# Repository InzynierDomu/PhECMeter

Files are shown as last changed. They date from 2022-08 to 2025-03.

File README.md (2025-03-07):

# PhECMeter







- [PhECMeter](#phecmeter)
  - [Description](#description)
    - [Future](#future)
  - [Scheme](#scheme)
    - [Part list](#part-list)
  - [IDE](#ide)
  - [Quick deployment without using VS Code environment](#quick-deployment-without-using-vs-code-environment)
    - [Requirements](#requirements)
    - [Usage](#usage)
    - [Notes](#notes)

## Description
The video with the entire project can be watched on this [video](https://youtu.be/vjk0nq04lCo)

The device has 4 possible states:
* measure pH
* measure EC
* calibartion pH
* calibration EC



The device start in pH measure mode. To chnage pH/EC measure mode - press up button for more than 1s.</br>
To enter calibration mode press both buttons more 1s.</br>
Measure pH -> calibration pH.</br>
Measure EC -> calibartion EC.</br>
Calibration mode needs 2 points to save.</br>
Set the value to which sample the probe is immersed. For that use up and dwn(down) buttons to decrease or increase the value. In EC calibration possible is to change the digit position by pressing 1s up button. To save points press 1s on both buttons. After saving two points, the device changes state to measure.</br>
</br>
When SD card is plugged, after short press down button measurements will be save in file on SD.

<div align="center">
<h2>Support</h2>

<p>If any of my projects have helped you in your work, studies, or simply made your day better, you can buy me a coffee. <a href="https://buycoffee.to/inzynier-domu" target="_blank">Postaw mi kawę na buycoffee.to</a></p>
</div>

### Future
* Use accumulator.
* Add some communication maybe RS232 or RS485.

## Scheme
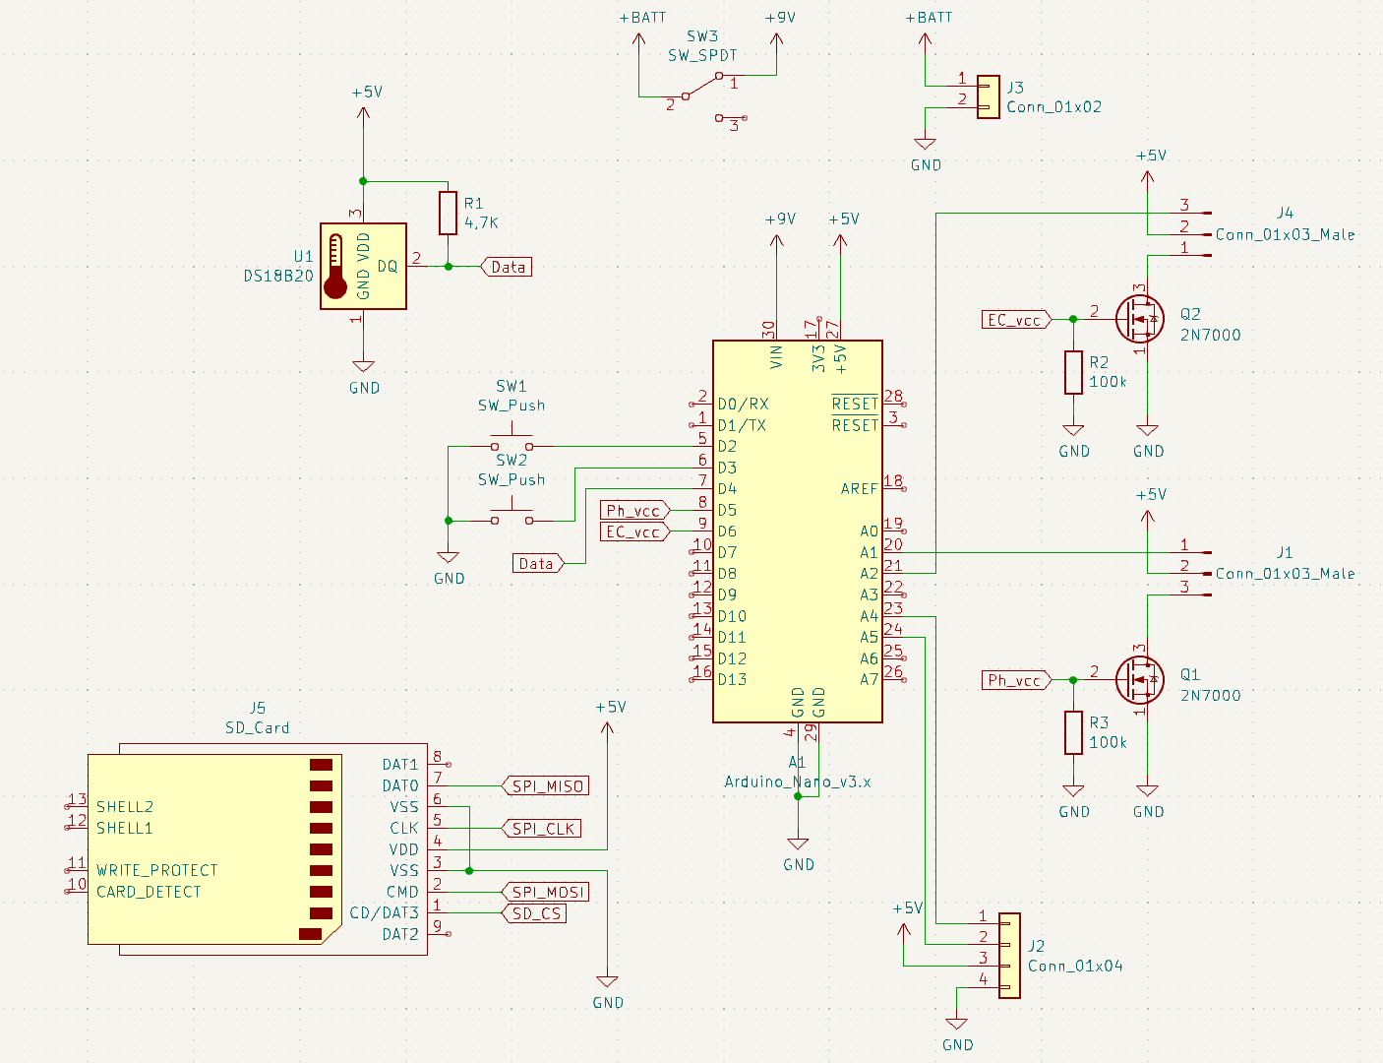
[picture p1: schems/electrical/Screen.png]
schem

### Part list
* pH probe and board like [this](https://botland.com.pl/pl/seria-gravity/15094-gravity-czujnik-miernik-ph-analogowy-v2-dfrobot-sen0161-v2.html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)
* EC probe and board like [this](https://botland.com.pl/gravity-czujniki-pogodowe/15096-gravity-analogowy-czujnik-zasolenia-wody-i-gleby-dfrobot-dfr0300-h-5904422348359.html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)
* A1 Arduino Nano
* U1 ds18b20 temperature sensor
* J1 is socket for pH board.
* J2 is socket for I2C screen OLED SSD1306 128x32 or HD44780 via PCF8574. 
* R1 Resistor 4,7 kohm
* SW1, SW2 micro switch
* SW3 switch to turning on/of power
* J3 connect to battery box
* J5 SD card socket (optional)

## IDE
If you prefer not to use the VS Code environment or prefer simpler solutions, you can use an [alternative approach](#quick-deployment-without-using-vs-code-environment)
For specific screen is the prepared environment:</br>
OLED SSD1306 128x32 :nanoatmega328_oled</br>
HD44780 via PCF8574 :nanoatmega328_lcd</br>
</br>
The project is prepared for the Platform IO environment. A video on how to install such an environment can be watched on this [video](https://youtu.be/Em9NuebT2Kc).
<br><br>
Formatting is done using clang-format. The description of the tool configuration is in the [video](https://youtu.be/xxuaOG0WjIE).
<br><br>
The code contains a comment prepared for doxygen, their use is described in the [video](https://youtu.be/1YKJtrCsPD4).

## Quick deployment without using VS Code environment
You don't need vscode, platformio is not needed, it will be installed with the script.

### Requirements
* Python 3.x must be installed on your computer. You can download the latest version of Python from Python.org.
### Usage
* Connect the Arduino board to your computer using a USB cable.
* Ensure that Python is available in the system environment.
* Run the autodeploy.bat file by double-clicking on it or running it from the command prompt (cmd). This script will automatically detect the connected Arduino board and upload the project to it.
### Notes
* It's version for oled.
* Make sure that the path to Python is added to the PATH environment variable in the Windows operating system.
* The atodeploy.bat script works only on Windows.

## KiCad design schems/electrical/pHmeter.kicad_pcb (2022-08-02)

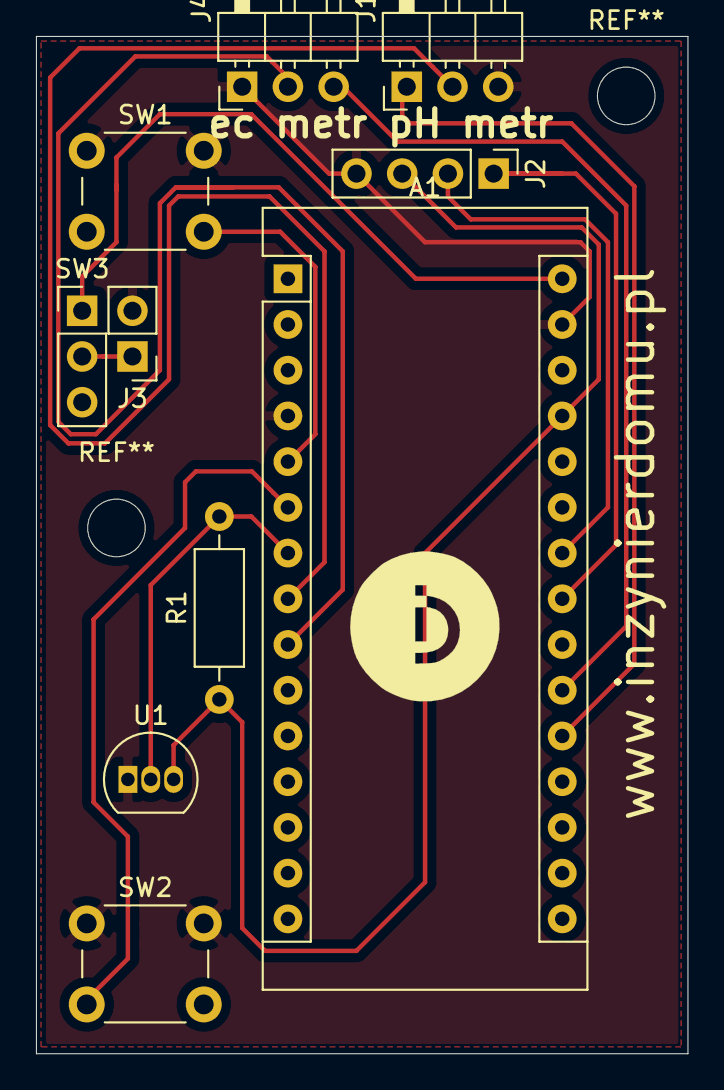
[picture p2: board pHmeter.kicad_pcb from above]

Board: 2 copper layers, 36.2 x 56.5 mm, 10 parts (0 on the bottom side), 13 nets.

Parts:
A1: Arduino_Nano_v3.x; Arduino_Nano
J1, J4: Conn_01x03_Male; PinHeader_1x03_P2.54mm_Horizontal
J2: Conn_01x04; PinHeader_1x04_P2.54mm_Vertical
J3: Conn_01x02; PinHeader_1x02_P2.54mm_Vertical
R1: 4,7K; R_Axial_DIN0207_L6.3mm_D2.5mm_P10.16mm_Horizontal
SW1, SW2: SW_Push; SW_PUSH_6mm_H8mm
SW3: SW_SPDT; PinHeader_1x03_P2.54mm_Vertical
U1: DS18B20; TO-92_Inline

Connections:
+5V: A1.27, J2.3, R1.1, U1.3
+9V: A1.30, SW3.1
+BATT: J3.1, SW3.2
Data: A1.7, R1.2, U1.2
EC_vcc: A1.9, J4.2
GND: A1.4, A1.29, J1.3, J2.4, J3.2, J4.1, SW1.1, SW2.1, U1.1
unnamed: A1.5, SW1.2
unnamed: A1.6, SW2.2
unnamed: A1.20, J1.1
unnamed: A1.21, J4.3
unnamed: A1.23, J2.1
unnamed: A1.24, J2.2
Ph_vcc: A1.8, J1.2

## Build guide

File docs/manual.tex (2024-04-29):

\documentclass{article}
\usepackage{graphicx}
\title{pH EC meter - Manual}
\author{Inżynier Domu - Szymon Markiewicz}
\date{October 2022}
\begin{document}
\maketitle
\tableofcontents

\section{Installation}
If you prefer not to use the VS Code environment or prefer simpler solutions, you can use an \href{#quick-deployment-without-using-vs-code-environment}{alternative approach}.

For specific screen is the prepared environment:
\begin{itemize}
    \item OLED SSD1306 128x32 : \texttt{nanoatmega328\_oled}
    \item HD44780 via PCF8574 : \texttt{nanoatmega328\_lcd}
\end{itemize}

The project is prepared for the Platform IO environment. A video on how to install such an environment can be watched on this \href{https://youtu.be/Em9NuebT2Kc}{video}.

\subsection{Quick deployment without using VS Code environment}
You don't need vscode, platformio is not needed, it will be installed with the script.

\subsubsection{Requirements}
\begin{itemize}
    \item Python 3.x must be installed on your computer. You can download the latest version of Python from \href{https://www.python.org}{Python.org}.
\end{itemize}

\subsubsection{Usage}
\begin{itemize}
    \item Connect the Arduino board to your computer using a USB cable.
    \item Ensure that Python is available in the system environment.
    \item Run the autodeploy.bat file by double-clicking on it or running it from the command prompt (cmd). This script will automatically detect the connected Arduino board and upload the project to it.
\end{itemize}

\subsubsection{Notes}
\begin{itemize}
    \item It's version for OLED.
    \item Make sure that the path to Python is added to the PATH environment variable in the Windows operating system.
    \item The atodeploy.bat script works only on Windows.
\end{itemize}

\section{Usage}
The video with the entire project can be watched on this \href{https://youtu.be/vjk0nq04lCo}{video}.

The device has 4 possible states:
\begin{itemize}
    \item measure pH
    \item measure EC
    \item calibration pH
    \item calibration EC
\end{itemize}

The device starts in pH measure mode. To change pH/EC measure mode - press the up button for more than 1 second. To enter calibration mode, press both buttons for more than 1 second. 
\begin{itemize}
    \item Measure pH -> calibration pH.
    \item Measure EC -> calibration EC.
\end{itemize}
Calibration mode requires 2 points to be saved.

Set the value to which the sample probe is immersed. Use the up and down buttons to decrease or increase the value. In EC calibration, it is possible to change the digit position by pressing the up button for 1 second. To save points, press both buttons for 1 second. After saving two points, the device changes state to measure.

When an SD card is plugged in, after a short press of the down button, measurements will be saved in a file on the SD card.

\end{document}

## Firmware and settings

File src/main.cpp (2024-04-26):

/**
 * @file main.cpp
 * @author by Szymon Markiewicz (https://github.com/InzynierDomu/)
 * @brief pH and EC meter
 * @date 2022-06
 */

#include "Buttons.h"
#include "Calibration_data_memory.h"
#include "Config.h"
#include "DS18B20.h"
#include "Data_presentation.h"
#include "Linear_function.h"
#include "OneWire.h"
#include "Sd_card.h"

#include <Arduino.h>
#include <EEPROM.h>
#include <math.h>

///< possible device state
enum class Device_state
{
  startup,
  display_measure_ph,
  display_measure_ec,
  calibration_ph,
  calibration_ec
};

byte m_ds_address[8]; ///< ds18b20 thermometer one wire address
OneWire m_one_wire = OneWire(Config::pin_thermometer); ///< one wire bus
DS18B20 m_ds_sensor = DS18B20(Config::pin_thermometer); ///< ds18b20 thermometer
Data_presentation m_data_presentation; ///< screen and serial handling
Calibration_data_memory m_memory; ///< memory handling
Sd_card m_sd_card; ///< sd crad handling

Device_state m_device_state = Device_state::startup; ///< actual device state

volatile bool m_up_button_pressed = false; ///< right button pressed flag
volatile bool m_dwn_button_pressed = false; ///< left button pressed flag
Linear_function ph_probe_characteristic; ///< ph probe linear characteristic
Linear_function ec_probe_characteristic; ///< ec probe linear characteristic

/**
 * @brief find thermometer on one wire
 */
void ds_thermometer_init()
{
  m_one_wire.reset_search();
  while (m_one_wire.search(m_ds_address))
  {
    if (m_ds_address[0] != 0x28)
      continue;

    if (OneWire::crc8(m_ds_address, 7) != m_ds_address[7])
    {
      break;
    }
  }
}

/**
 * @brief right button press interrupt
 */
void button_r_pressed()
{
  m_up_button_pressed = true;
}

/**
 * @brief left button press interrupt
 */
void button_l_pressed()
{
  m_dwn_button_pressed = true;
}

/**
 * @brief ph measure
 * @param action: buttons action
 */
void measurements_ph(const Buttons_action action)
{
  float temperature = m_ds_sensor.getTempC();
  int analog_mes = analogRead(Config::ph_pin_probe);
  float ph = ph_probe_characteristic.find_unit_val(analog_mes);

  m_data_presentation.measurements_ph(temperature, ph);

  switch (action)
  {
    case Buttons_action::two_buttons_long:
      m_data_presentation.calibration_mode();
      m_device_state = Device_state::calibration_ph;
      break;
    case Buttons_action::up_button_long:
      digitalWrite(Config::ph_supply_pin_probe, LOW);
      digitalWrite(Config::ec_supply_pin_probe, HIGH);
      m_device_state = Device_state::display_measure_ec;
      break;
    case Buttons_action::short_dwn_button:
      if (m_sd_card.get_card_status())
      {
        m_sd_card.save_ph_measurement(temperature, ph);
        m_data_presentation.save_data();
      }
      break;
    default:
      m_device_state = Device_state::display_measure_ph;
      break;
  }
}

/**
 * @brief ec measure
 * @param action: buttons action
 */
void measurements_ec(const Buttons_action action)
{
  float temperature = m_ds_sensor.getTempC();
  int analog_mes = analogRead(Config::ec_pin_probe);
  float ec = ec_probe_characteristic.find_unit_val(analog_mes);

  m_data_presentation.measurements_ec(temperature, ec);

  switch (action)
  {
    case Buttons_action::two_buttons_long:
      m_data_presentation.calibration_mode();
      m_device_state = Device_state::calibration_ec;
      break;
    case Buttons_action::up_button_long:
      digitalWrite(Config::ec_supply_pin_probe, LOW);
      digitalWrite(Config::ph_supply_pin_probe, HIGH);
      m_device_state = Device_state::display_measure_ph;
      break;
    case Buttons_action::short_dwn_button:
      if (m_sd_card.get_card_status())
      {
        m_sd_card.save_ec_measurement(temperature, ec);
        m_data_presentation.save_data();
      }
      break;
    default:
      m_device_state = Device_state::display_measure_ec;
      break;
  }
}

/**
 * @brief saving next point in characteristic
 * @param samples points to characteristic
 * @param sample new reference value
 * @return is calibration finished
 */
bool save_sample(Point* samples, double sample)
{
  static int sample_counter = 0;
  samples[sample_counter].unit_val = sample;
  switch (m_device_state)
  {
    case Device_state::calibration_ph:
      samples[sample_counter].analog_val = analogRead(Config::ph_pin_probe);
      break;
    case Device_state::calibration_ec:
      samples[sample_counter].analog_val = analogRead(Config::ec_pin_probe);
      break;
    default:
      break;
  }

  if (++sample_counter == 2)
  {
    sample_counter = 0;
    return true;
  }
  return false;
}

/**
 * @brief load old ph calibration unit value
 * @param point first or second point
 * @return double unit value for specify point
 */
double load_ph_point(uint8_t point)
{
  Point points[2];
  m_memory.load_ph_calibration(points);
  return points[point].unit_val;
}

/**
 * @brief calibration ph procedure
 * @param action buttons action
 */
void calibration_ph(const Buttons_action action)
{
  static uint8_t sample = load_ph_point(0);

  static Point samples[2] = {};

  float temperature = m_ds_sensor.getTempC();

  switch (action)
  {
    case Buttons_action::two_buttons_long:
      m_data_presentation.save_data();
      if (save_sample(samples, sample))
      {
        m_memory.save_ph_calibration(samples);
        ph_probe_characteristic.set_points(samples);
        sample = samples[0].unit_val;
        m_device_state = Device_state::display_measure_ph;
      }
      else
      {
        sample = load_ph_point(1);
      }
      break;
    case Buttons_action::short_dwn_button:
      if (sample > 1)
      {
        sample--;
      }
      break;
    case Buttons_action::short_up_button:
      if (sample < Config::max_ph_to_calib)
      {
        sample++;
      }
      break;
    default:
      auto read_val = analogRead(Config::ph_pin_probe);
      m_data_presentation.calibration_ph(sample, temperature, read_val);
      break;
  }
}

/**
 * @brief load old ec calibration unit value
 * @param point first or second point
 * @return double unit value for specify point
 */
double load_ec_point(uint8_t point)
{
  Point points[2];
  m_memory.load_ec_calibration(points);
  return points[point].unit_val;
}

/**
 * @brief calibration ec procedure
 * @param action buttons action
 */
void calibration_ec(const Buttons_action action)
{
  static double sample = load_ec_point(0);
  static uint8_t position = 0;

  static Point samples[2] = {};

  float temperature = m_ds_sensor.getTempC();

  switch (action)
  {
    case Buttons_action::two_buttons_long:
      m_data_presentation.save_data();
      if (save_sample(samples, sample))
      {
        m_memory.save_ec_calibration(samples);
        ec_probe_characteristic.set_points(samples);
        sample = samples[0].unit_val;
        m_device_state = Device_state::display_measure_ec;
      }
      else
      {
        sample = load_ec_point(1);
      }
      break;
    case Buttons_action::short_dwn_button:
      if (sample > Config::min_ec_to_calib)
      {
        sample = sample - pow(10.0, position * (-1.0));
      }
      break;
    case Buttons_action::short_up_button:
      if (sample < Config::max_ec_to_calib)
      {
        sample = sample + pow(10.0, position * (-1.0));
      }
      break;
    case Buttons_action::up_button_long:
      if (position < 3)
      {
        position++;
      }
      else
      {
        position = 0;
      }
      break;
    default:
      auto read_val = analogRead(Config::ec_pin_probe);
      m_data_presentation.calibration_ec(sample, position, temperature, read_val);
      break;
  }
}

/**
 * @brief setup on startup
 */
void setup()
{
  m_data_presentation.init();
  ds_thermometer_init();

  if (m_sd_card.is_card_available())
  {
    Serial.println("SD card is present");
  }

  Point points[2];
  m_memory.load_ph_calibration(points);
  ph_probe_characteristic.set_points(points);
  m_data_presentation.print_ph_calibration(points);
  m_sd_card.print_ph_calibration(points);

  m_memory.load_ec_calibration(points);
  ec_probe_characteristic.set_points(points);
  m_data_presentation.print_ec_calibration(points);
  m_sd_card.print_ec_calibration(points);

  pinMode(Config::ph_supply_pin_probe, OUTPUT);
  digitalWrite(Config::ph_supply_pin_probe, HIGH);
  pinMode(Config::ec_supply_pin_probe, OUTPUT);
  digitalWrite(Config::ec_supply_pin_probe, LOW);
  pinMode(Config::pin_up_button, INPUT_PULLUP);
  pinMode(Config::pin_dwn_button, INPUT_PULLUP);
  attachInterrupt(digitalPinToInterrupt(Config::pin_up_button), button_r_pressed, FALLING);
  attachInterrupt(digitalPinToInterrupt(Config::pin_dwn_button), button_l_pressed, FALLING);

  m_device_state = Device_state::display_measure_ph;
}

/**
 * @brief main loop with state machine
 */
void loop()
{
  Buttons_action action = Buttons_action::nothing;
  if (m_up_button_pressed || m_dwn_button_pressed)
  {
    action = Buttons::check_buttons(m_up_button_pressed, m_dwn_button_pressed);
    if (action != Buttons_action::nothing)
    {
      m_up_button_pressed = false;
      m_dwn_button_pressed = false;
      delay(100);
    }
  }

  switch (m_device_state)
  {
    case Device_state::display_measure_ph:
      measurements_ph(action);
      break;
    case Device_state::display_measure_ec:
      measurements_ec(action);
      break;
    case Device_state::calibration_ph:
      calibration_ph(action);
      break;
    case Device_state::calibration_ec:
      calibration_ec(action);
      break;
    default:
      break;
  }
}

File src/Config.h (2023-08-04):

/**
 * @file Config.cpp
 * @author by Szymon Markiewicz (https://github.com/InzynierDomu/)
 * @brief device configuration
 * @date 2022-06
 */
#pragma once

#include <Arduino.h>
#include <stdint.h>


namespace Config
{
const uint8_t pin_up_button = 3; ///< up button pin number
const uint8_t pin_dwn_button = 2; ///< down button pin number
const uint8_t pin_thermometer = 4; ///< ds18b20 thermometer pin number
const uint8_t ph_pin_probe = 15; ///< ph probe pin
const uint8_t ec_pin_probe = 16; ///< ec probe pin
const uint8_t ph_supply_pin_probe = 5; ///< ph probe supply pin
const uint8_t ec_supply_pin_probe = 6; ///< ec probe supply pin
const uint8_t sd_card_cs_pin = 7; ///< cs pin in spi communication to sd card

const uint8_t screen_address = 0x3C; ///< ssd1306 oled screen i2c address
const uint8_t screen_width = 128; ///< screen width
const uint8_t screen_height = 32; ///< screen height

const uint8_t blink_time_calibration = 150; ///< toggling digits in calibration mode time
const uint16_t long_press_time = 1000; ///< time for long buttons press
const uint8_t max_ph_to_calib = 24; ///< max ph to set in calibration
const uint8_t max_ec_to_calib = 64; ///< max ec to set in calibration
const uint8_t min_ec_to_calib = 0;

const String file_name = "data.log"; ///< file name on SD card to save measurments

} // namespace Config

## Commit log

2020-11-21 move liner function and add smal delay to easy calibration
2021-01-04 Add pin to supply ph sonde
2021-05-16 add ec metr and button actions
2022-06-20 fix changing mode ec/ph
    [Config.h, Data_presentation.cpp, main.cpp]
2022-06-20 remove arduino stl
2022-06-23 add EC calibration
2022-07-11 update buttons names
2022-07-28 Move button handling to other files
2022-08-01 fix button naming
2022-08-02 add schems
    [pHmeter.kicad_pcb, pHmeter.sch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]
2022-08-26 fix main buttons issues
    [Buttons.cpp, Config.h, main.cpp]
2022-08-29 update schem
    [pHmeter.sch]
2022-08-30 update calibration
2022-09-02 save calibration fix
2022-09-07 clean buttons actions
2022-09-13 fix ec calibration
2022-09-13 clear folders
    [pHmeter.kicad_pcb, pHmeter.sch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]
2022-10-18 add print calibration data on start
2024-04-26 add load old values in calibration mode
2024-04-26 fix next load old values in calibration mode
    [main.cpp]
